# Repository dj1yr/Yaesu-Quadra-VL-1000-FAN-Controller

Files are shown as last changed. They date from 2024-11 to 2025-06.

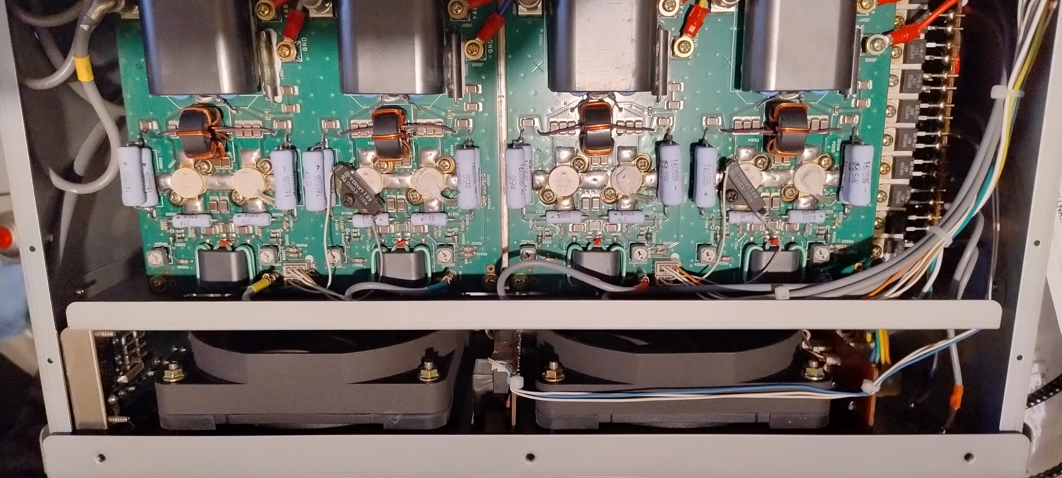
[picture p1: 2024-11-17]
IMG_20241115_050730921_HDR.jpg

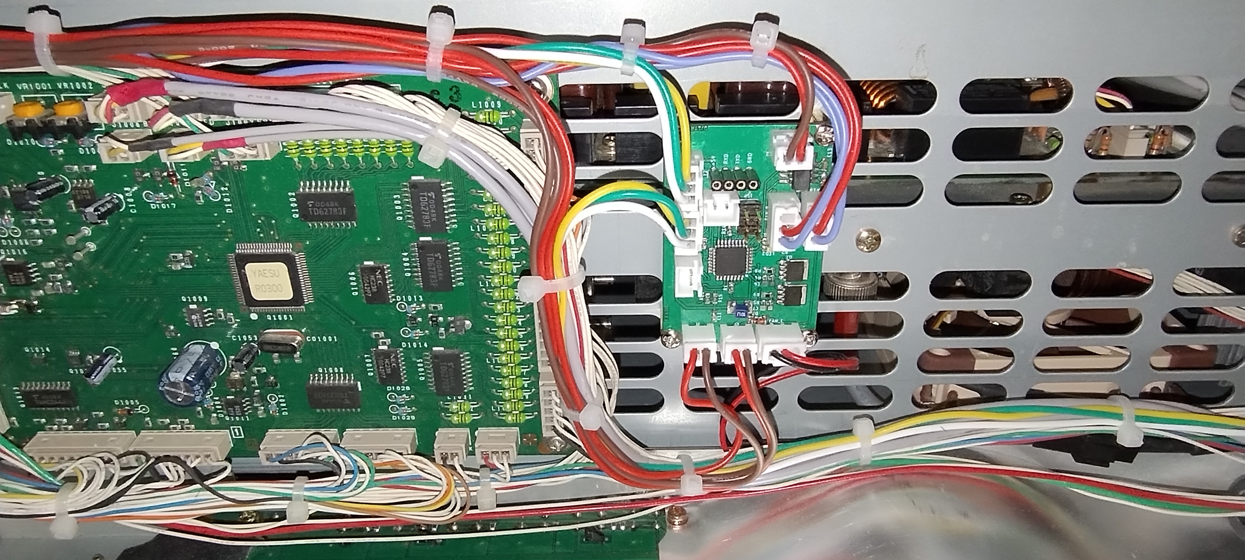
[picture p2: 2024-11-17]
IMG_20241115_045521945.jpg

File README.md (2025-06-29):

# Yaesu-Quadra-VL-1000-FAN-Controller

Hi,

I have had a Quadra with a late serial number for a long time.
It's a nice PA that I really enjoy using, but what has always bothered me a lot is the PA's fan noise, the fans are always running at full speed.
These are controlled by the µC of the PA, this switches the fans on, I have checked this chain, everything is in order and there is no defect (µC -> Q8004 etc.)
Why Yaesu has solved this in this way is a mystery to me.

I have started to design a fan controller that uses the original connections so that no changes need to be made to the original hardware.

The controller is based on an Atmega8, 2x I2C temperature sensors (DS18B20) and two PWM FET stages. (FAN A+B and FAN C)
One temperature sensor is attached to the RF block, one to the tuner.

Unfortunately, the original fans, which are actually very good, cannot be throttled, they then make a lot of noise. 
I have replaced my fans with Noctua NF-A12-25 in black and the FAN C with Noctua NF-A8 PWM chromax.black.swap,
these have a good static pressure with low noise and can be regulated very well (I like to use them in other PA projects).

The controller controls the fans, the lower limit temperature is 20°C, from this point the fans switch off, when PTT is on, both fans are controlled with 10% FAN C or 20% FAN A+B, when the temperature rises the fans turn faster, at approx. 40°C the fans run at maximum.
FAN C is PTT dependent, fans A+B run independently.
There is also a switching output that can be connected in parallel to “PA-ALM” (J1009/J1010), which would set the PA to overtemperature protect mode if limit values/heat sensors are exceeded.
A query of the fan speed has been prepared, but is not yet evaluated.

The QRL gives me the opportunity to take flow measurements, and I noticed that the two rear fans influence each other, that they can “see” each other, i.e. the air flow is partially canceled out and the efficiency drops by 20% in some cases.
I made two fan frames for my PA (3d printed at JLPCB), which reduced the problem to <2% influence.

So far everything is working fine, the PA doesn't get any warmer than before (checked with IR camera) and is now finally quiet.

The project was originally created in Eagle, then converted to KICAD, the software is written in the Arduino IDE, the fan frame in Inventor.

73´ René

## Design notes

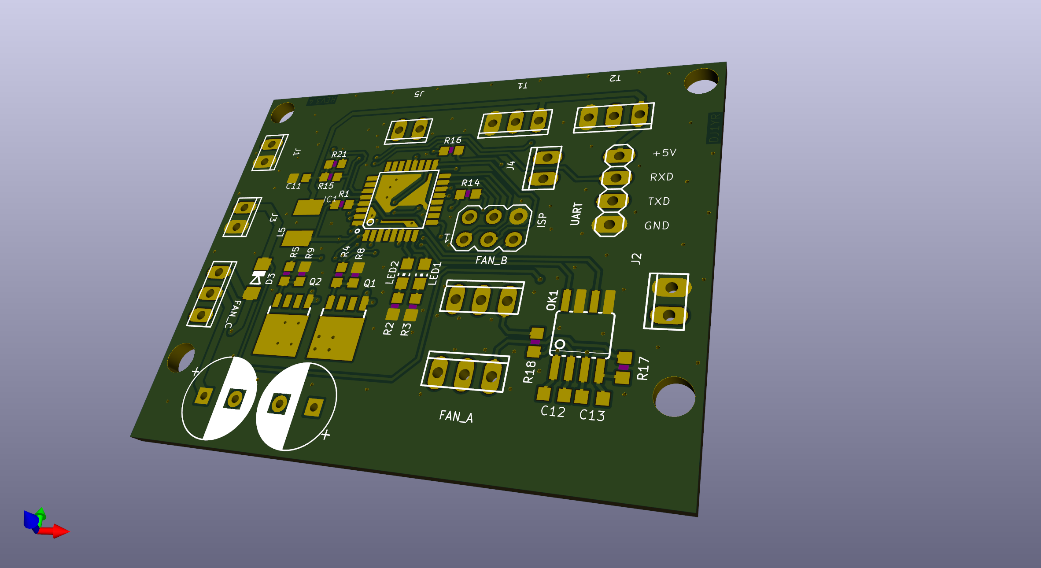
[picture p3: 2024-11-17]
Quadra FAN CNTL.png

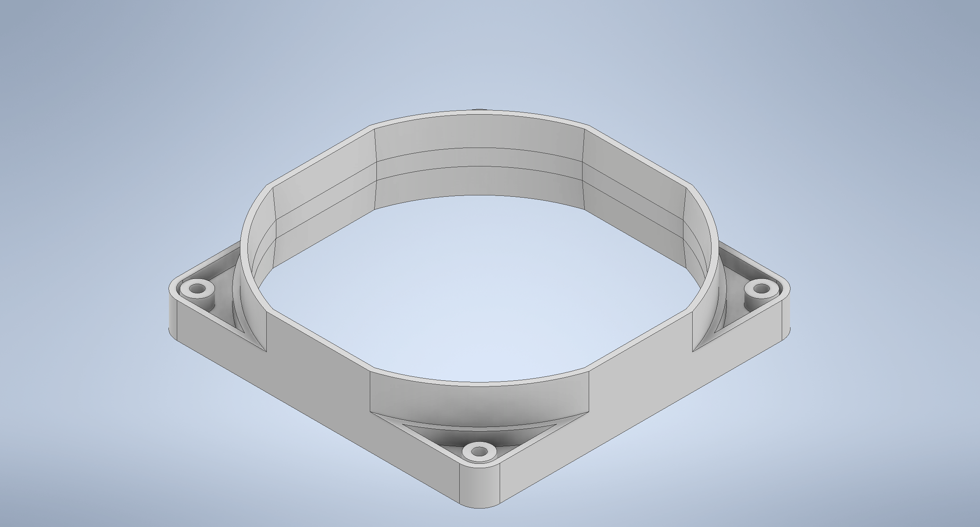
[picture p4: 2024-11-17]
Fan Mod.png

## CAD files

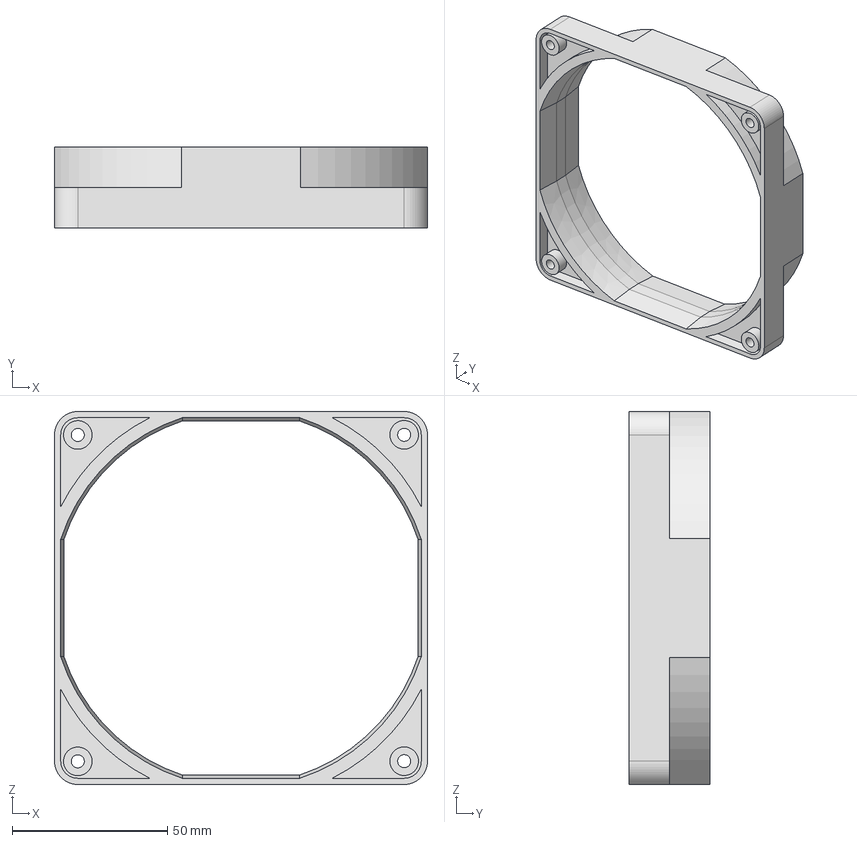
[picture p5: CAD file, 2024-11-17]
Fan Mod.stp
120.0 x 26.0 x 120.0 mm

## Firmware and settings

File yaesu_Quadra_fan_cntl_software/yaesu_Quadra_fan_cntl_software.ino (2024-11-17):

//*************************************************************************************************
//This is a simple temperature conrolled fan controller for Yaesu VL1000 an other pa´s.
//The program reading two I2C temperature sensors, like DS18B20.
//It must no set I2C adress in a register, read_sens setting this automaticly.
//Will you read data with UART, must set the debug = 1, uart is set to 9600 baud.
//When it have a read error of temperature sensors or over/under temperature, 
//is set error = 1 and overtemp output to high, fan´s are running full speed 
//The overtemp output can  connect to overtemp connector from VL-1000,
//this will set the PA in error mode.
//73´DJ1YR(René)
//*************************************************************************************************

#include <OneWire.h>
#include <DallasTemperature.h>

OneWire  ds_c(19);                    //DS18B20 Tuner Unit
OneWire  ds_ab(18);                   //DS18B20 RF Block

unsigned long previousMillis_temp = 0; 
const long interval_temp = 500;           //read intervall of temp sensors in ms 

const int fan_ab_speed = 2;               //on pin 32
const int fan_c_speed = 3;                //on pin 1
const int overtemp = 4;                   //on pin 4
const int reserve_0 = 8;                  //on pin 12
const int LED_1 = 20;                     //on pin 7
const int LED_2 = 21;                     //on pin 8
int LED_1_state = LOW;                    //debug led for "life pulse"
int LED_2_state = LOW;                    //debug led

const int fan_ab = 10;
int fan_ab_pwm;
int fan_ab_ptt_min = 20;                  //<---- minimal pwm for pa fan on vl-1000 when tx is enabled
const int fan_c = 9;
int fan_c_pwm;
int fan_c_ptt_min = 10;                   //<---- minimal pwm for atu fan on vl-1000 when tx is enabled

const int tx_in = 5;                      

bool tx_stat = 0;
bool ok = 0;
bool debug = 0;                           //<-------set this for debuging
bool error = 0;

//******* temperature sensor RF BLOCK ************
byte i_ab;
byte present_ab = 0;
byte type_s_ab;
byte data_ab[9];
byte addr_ab[8];
float temp_ab;

//******* temperature sensor Tuner ***************
byte i_c;
byte present_c = 0;
byte type_s_c;
byte data_c[9];
byte addr_c[8];
float temp_c;

//********** temperature limits **************
int temp_min_ab = 15;
int temp_max_ab = 45;
int temp_min_c = 15;
int temp_max_c = 45;

void setup() {
  Serial.begin(9600);
  
  pinMode(fan_ab_speed, INPUT);
  pinMode(fan_c_speed, INPUT);
  pinMode(overtemp, OUTPUT);
  pinMode(reserve_0, OUTPUT);
  pinMode(LED_1, OUTPUT);
  pinMode(LED_2, OUTPUT);
  pinMode(fan_ab, OUTPUT);
  pinMode(fan_c, OUTPUT);
  pinMode(tx_in,INPUT_PULLUP);
}

void loop() {
  
tx_stat = digitalRead(tx_in);
//*******PA_Start********** 
 
  
  if (debug == 0&&ok == 0) {
    fan_ab_pwm = 255;
    fan_c_pwm = 255;    
    analogWrite(fan_ab, fan_ab_pwm);
    analogWrite(fan_c, fan_c_pwm); 
    delay(5000);
    ok = 1;
    fan_ab_pwm = 0;
    fan_c_pwm = 0;    
    analogWrite(fan_ab, fan_ab_pwm);
    analogWrite(fan_c, fan_c_pwm); 
  }

//*************************
  
  if (ok == 1&&error == 0) { 
    digitalWrite(overtemp,LOW);  
    unsigned long currentMillis_temp = millis();                    //Temperatur nur jede n Sekunde auslesen, wenn debuging aktiviert ist, kann es zu längeren Intervallen kommen, da ein delay von 1000ms hinzukommt
    if (currentMillis_temp - previousMillis_temp >= interval_temp) {
    previousMillis_temp = currentMillis_temp;
    meassure_temp();
    }
    else
    analogWrite(fan_ab_pwm, 255); 
    analogWrite(fan_c_pwm, 255);
    digitalWrite(overtemp,HIGH);
   }

    fan_ab_pwm = map(temp_ab, temp_min_ab, temp_max_ab, 0, 255);
    if (fan_ab_pwm <= 25) {
    fan_ab_pwm = 0;
    }
    
    fan_c_pwm = map(temp_c, temp_min_c, temp_max_c, 0, 255);
    if (fan_c_pwm <= 10) {
    fan_c_pwm = 0;
    }

    if (tx_stat == 0){
        if(fan_ab_pwm <=25){
           fan_ab_pwm = fan_ab_ptt_min;
           }
           
        if(fan_c_pwm <= 10){
           fan_c_pwm = fan_c_ptt_min;
           }
     }
    analogWrite(fan_ab, fan_ab_pwm);
    analogWrite(fan_c, fan_c_pwm); 
   
  if(debug){
    debuging();
  }
}

void meassure_temp() {

  if ( !ds_ab.search(addr_ab)) {
    ds_ab.reset_search();
    return;}

  if ( !ds_c.search(addr_c)) {
     ds_c.reset_search();
     return;}  
  
  if (OneWire::crc8(addr_ab, 7) != addr_ab[7]) {
     error = 1;
     return;}
  if (OneWire::crc8(addr_c, 7) != addr_c[7]) {
     error = 0;
     return;}
  
  ds_ab.reset();
  ds_ab.select(addr_ab);
  ds_ab.write(0x44, 1);                         // start conversion, with parasite power on at the end

  ds_c.reset();
  ds_c.select(addr_c);
  ds_c.write(0x44, 1);                          // start conversion, with parasite power on at the end
  
  present_ab = ds_ab.reset();
  ds_ab.select(addr_ab);    
  ds_ab.write(0xBE);                            // Read Scratchpad

  present_c = ds_c.reset();
  ds_c.select(addr_c);    
  ds_c.write(0xBE);                             // Read Scratchpad

  for ( i_ab = 0; i_ab < 9; i_ab++) {           // we need 9 bytes
    data_ab[i_ab] = ds_ab.read();}

  for ( i_c = 0; i_c < 9; i_c++) {              // we need 9 bytes
    data_c[i_c] = ds_c.read();}  

  int16_t raw_ab = (data_ab[1] << 8) | data_ab[0];
  if (type_s_ab) {
    raw_ab = raw_ab << 3;                       // 9 bit resolution default
    if (data_ab[7] == 0x10) {
      raw_ab = (raw_ab & 0xFFF0) + 12 - data_ab[6];
      }
    }
    
    int16_t raw_c = (data_c[1] << 8) | data_c[0];
  if (type_s_c) {
    raw_c = raw_c << 3;                         // 9 bit resolution default
    if (data_c[7] == 0x10) {
    raw_c = (raw_c & 0xFFF0) + 12 - data_c[6];
    }
  } 
  
  temp_ab = (float)raw_ab / 16.0;
  temp_c = (float)raw_c / 16.0;

  if(temp_ab <= -1 || temp_ab >= 61){
    error = 1;
  }
  else{
    error = 0;
  }
  if(temp_c <= -1 || temp_c >= 60){
    error = 1;
  }
  else{
    error = 0;
  }

  
    if (LED_1_state == LOW) {
      LED_1_state = HIGH;}
      else {
      LED_1_state = LOW;}
      digitalWrite(LED_1, LED_1_state);  
}

void debuging(){ 
   if (ok == 0){
    ok = 1;
    }
  Serial.print("Temp_ab = ");
  Serial.print(temp_ab);
  Serial.print("°C_ab, ");
  Serial.print("PWM_ab = ");
  Serial.print(fan_ab_pwm);
  Serial.println();
  Serial.print("Temp_c = ");
  Serial.print(temp_c);
  Serial.print("°C_c, ");
  Serial.print("PWM_c = ");
  Serial.print(fan_c_pwm);
  Serial.println();
  Serial.println();
  Serial.print("TXin = ");
  Serial.println(tx_stat);
  Serial.println();
  Serial.println();
  Serial.print("Stat = ");
  Serial.println(ok);
  Serial.println();
  Serial.println();
  
  delay(1000);
}

  
